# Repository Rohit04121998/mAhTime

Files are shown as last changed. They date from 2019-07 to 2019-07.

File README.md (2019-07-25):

# mAhTime

## Objective 

To calculate the battery life for a device using small batteries and in turn use the data to calculate for any bigger battery.

## Why do we need this?

The capacity of a battery is measured in Ah (ampere-hours, for large batteries) or mAh (milliampere-hours, for small batteries). This is usually mentioned on the battery or in the datasheets provided by the manufacturer. But the capacity changes depending on the age of the battery, operating conditions, slightly different chemical composition, etc. So it affects the final result.

To get the actual capacity (close-enough-value), measuring the same is the method. Different methods are there using which one can measure the capacity, for example, Coulomb counting, Voltage monitoring, etc. (Learn more here or here).

Here we use the second method; monitoring the terminal voltage when a known load (resistive) is connected.

## Method:

The batteries are charged and connected to a custom-designed shield for the ESP8266 microcontroller and a load is selected using a button. The microcontroller logs the terminal voltage read from its pin to the MQTT broker in RPi until the lower cut off voltage for the batteries is reached. The loads are automatically disconnected using logic level p-MOS switches. 

The values read by the microconttrollr is sent to a RPi using a MQTT broker named **mosquitto**. MQTT is a pub-sub based protocol where one device reads and sends the data to a topic and another device subscribes to the same topic to get the data published by the first device. A brief explanation of how values are sent via a broker is explained in the next heading. The recieved data is run through a python script to display the discharge curve and the area under the curve is calculated(area under the V*I v/s t curve is power rating and area under the I v/s t curve is the mAh / Ah of the batteries).

Once again the batteries are charged, but this time, Device Under Test (DUT) is selected instead of a load (using the same microcontroller). The time taken for the DUT to discharge the batteries is found. This can then be used to calculate the life of any battery using ratios ( Eg.: If for X (mAh) it is Y (no. of days) then for Z (mAh)? = YZ/X ).

## MQTT

MQTT is one of the most commonly used protocols in IoT projects. It stands for Message Queuing Telemetry Transport.

  In addition, it is designed as a lightweight messaging protocol that uses publish/subscribe operations to exchange data between clients and the server. Furthermore, its small size, low power usage, minimized data packets and ease of implementation make the protocol ideal of the “machine-to-machine” or “Internet of Things” world.

## WHY MQTT??

MQTT has unique features you can hardly find in other protocols, like:

* It’s a lightweight protocol. So, it’s easy to implement in software and fast in data transmission.
* It’s based on a messaging technique. You know how fast your messenger/WhatsApp message delivery is. MQTT protocol is a similar one.
* Minimized data packets. Hence, low network usage.
* Low power usage. As a result, it saves the connected device’s battery.

## How MQTT works
Like any other internet protocol, MQTT is based on clients and a server. The server is the guy who is responsible for handling the client’s requests of receiving or sending data between each other. MQTT server is called a broker and the clients are simply the connected devices.

#### So:

When a device (a client) wants to send data to the broker, we call this operation a *“Publish”* and the device *"Publisher"*.
When a device (a client) wants to receive data from the broker, we call this operation a *“Subscribe”* and this device as *"Subscriber"*.

  
  
 ## MQTT Components

* *Broker*, which is the server that handles the data transmission between the clients.
* A *Topic*, which is the place a device want to put or retrieve a message to/from.
* The *Message*, which is the data that a device receives “when subscribing” from a topic or send “when publishing” to a topic.
* *Publish*, is the process a device does to send its message to the broker.
* *Subscribe*, where a device does to retrieve a message from the broker.

*By now hopefully you would have an idea how a MQTT network might look or works like.* 

  The common methods used to transfer data are:
  
  * Making use of [test.mosquitto.org](http://test.mosquitto.org/) server as a MQTT broker and sending the data via this server.
  
  * Making use of a common WiFi network to share the data.
  
  * Making one of the ends (i.e either ESP8266 or the RPi) as an *Access Point* and connect the other to it.
  
    The 2nd and the 3rd methods do not use any online brokers. Therefore a broker is to be installed in the RPi. For information on how to install mosquitto broker on your RPi use the link [Getting Started with Mosquitto MQTT Broker on a Raspberry Pi](https://www.youtube.com/watch?v=AsDHEDbyLfg&t=72s).

## Hardware & Firmware:

A microcontroller unit (ESP8266-12E on LOLin board) has an inbuilt ADC (Analog to Digital Converter) with a precision of (1/1024)th of a volt. But the input voltage range is only 0 (0) - 1V (1024). To use this in 0 - 3V range a resistor voltage divider is implemented using precision resistors and an n- MOS switch to enable this voltage divider. The voltage divider is not the one which is present on the LOLin board. Those are not precision resistors, hence the readings may not be accurate. The n-MOS switch is required as the voltage divider acts as another resistive load parallel to the selected load. An OLED display is used to display the selected load, time, etc.

The hardware limits the maximum battery voltage to 3.6V as the battery voltage appears at pin A0 when voltage divider is disabled and the absolute maximum voltage given is 3.6V for ESP8266. The time taken for measurement is determined by the capacity of the battery and the chosen load.

The circuit connections and the designed PCB can be found in the directory PCB_KICAD. The details about the charger and the battery can be found in the 'Charger_hacked' directory. 
Arduino IDE is used to program the microcontroller. The required header files and libraries are in the *upload_voltage* directory.

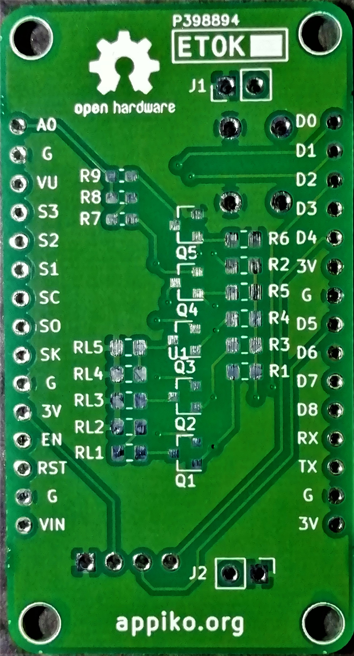
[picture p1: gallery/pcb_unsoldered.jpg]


### <p align="center">Fig 1. Unsoldered PCB</p>

PCB Front             |  PCB Back              
:-------------------------:|:-------------------------:
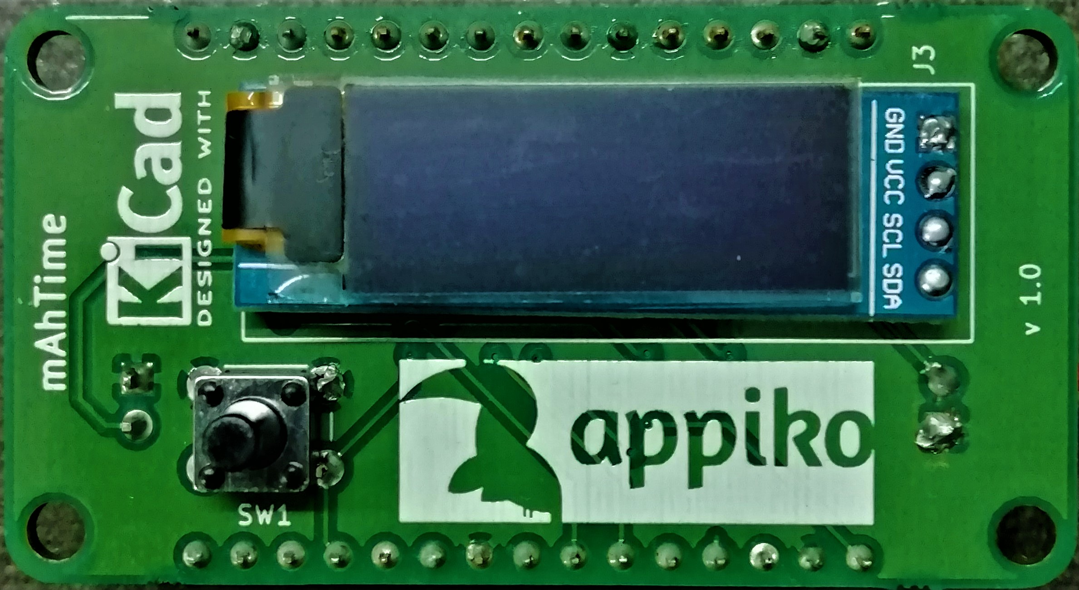
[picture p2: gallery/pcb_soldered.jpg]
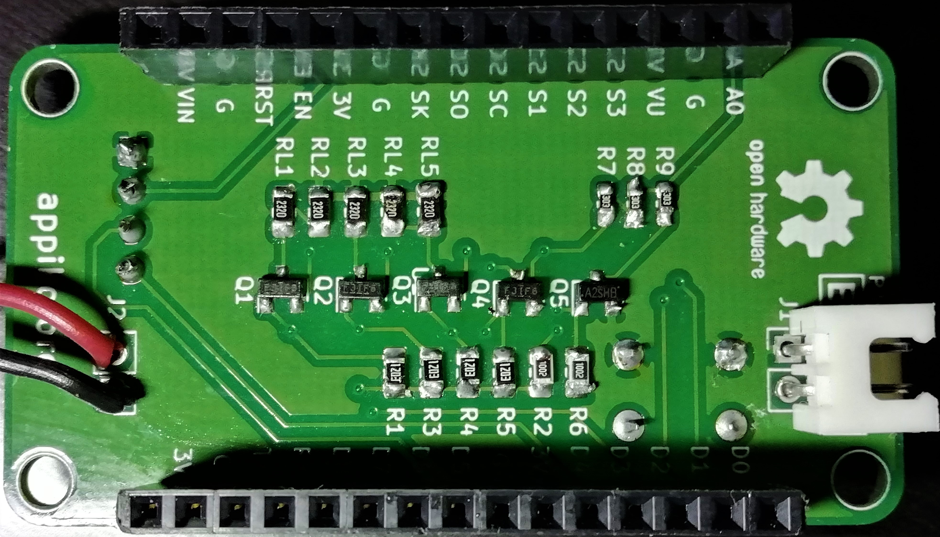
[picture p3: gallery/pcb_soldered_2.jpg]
 |   

### <p align="center">Fig 2. Soldered PCB</p>

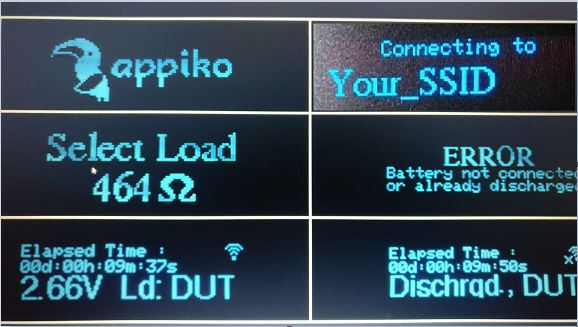
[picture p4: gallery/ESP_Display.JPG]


### <p align="center">Fig 3. Display</p>

## Code:

* In the *upload_voltage.ino* file, **Vbat** variable is used to store the voltage value. The queue is sized to hold a maximum of 1000 values. Here, the value is stored and sent every 4 seconds.

* To get the date and time info from the ESP8266, *NTTP Client* has been used . The *getFormattedDate()* function gives the date and time format as 2018-05-28T10:00:13Z. So modifications were done and the final output was  2018-05-28_10:00:13. This was further modified in the *plot.py* by replacing ':' with 'H', 'M' and 'S'. This was then appended to the *.csv* file having the load value as its initial name.

* The code is made such that a short press of the button is conssidered as next option and a long press is considered as select. The long press for one of the load values sets the value of variable *seleted* to a umber between 1 and 8. The load is selected according to the value of variable *selected* in the function *LoadVal*. The function *attachLoad* attaches the load and changes the state of the mosfets accordingly. The discharging of the battery starts as soon as the load is attached.

* Before any value is sent through MQTT, the variable *filename* which contains the device ID, load, date and time with the .csv extension is published to inform the subscriber that a new discharge cycle has started and to create a new CSV file by the name of the variable sent. Only after the filename are the voltage values to be sent.

* Once all the values are sent over through MQTT, a "Fully Discharged" message is sent stating that te experiment's finished.

* The code for MQTT subscribe is a simple code which tells the interpreter what to do when the connection with the MQTT broker is established and when a message is recieved. The funtion on_connect will be executed as soon as connection is established. The on_message funtion is executed as soon as a message is received. The messaged is checked for a **.csv** extension and a new CSV file is created if the result of this comparision is positive.

* This message with a .csv extension contains the ID of the device which published the message,the load selected, date and time of the moment a load is selected. The name of the new CSV file created contains only load,date and time(format containing 'H' 'M' and 'S' specified in one of the above points. Here data and time are included to differentiate between experiments conducted on the same day.

* The voltage values received are added to this file along with the time elapsed. At the end of the experiment "FUlly Discharged" message is recieved once and is added to the file informing the plotter that the experiment is finished and the mAh value can be calculated.

* In the script Plot_value.py **FuncAnimate** function is used to create an interactive mode i.e to plot a real time graph. The mAh value of the battery is shown only when the message "Fully Discharged" intercepts by the interpreter.

## Result:

  The result of the experments need not be the same everytime. The mAh value might change if the battery is not fully charged before the start of the experiment. The time taken for the discharge and the numbeer of voltage values recorded varies if a different load value is used or if the initial voltage of the battery is different.

The device was tested for 3 different loads and the graph plotted were as follows:

**Load**             |  093 Ohms             |  161 Ohms(Not fully charged)                                   
:-------------------------:|:-------------------------:|:-------------------------:
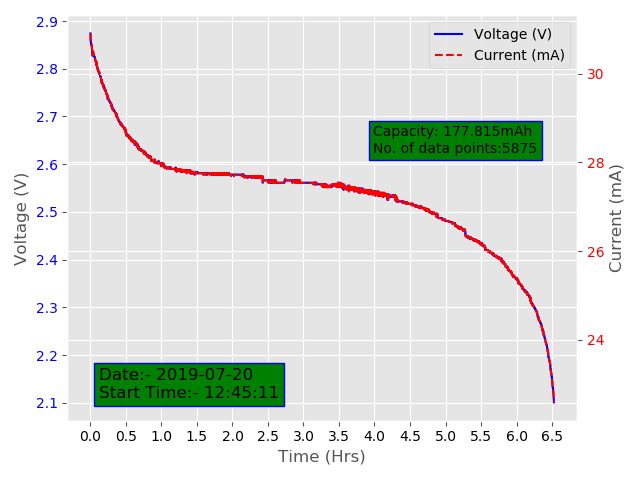
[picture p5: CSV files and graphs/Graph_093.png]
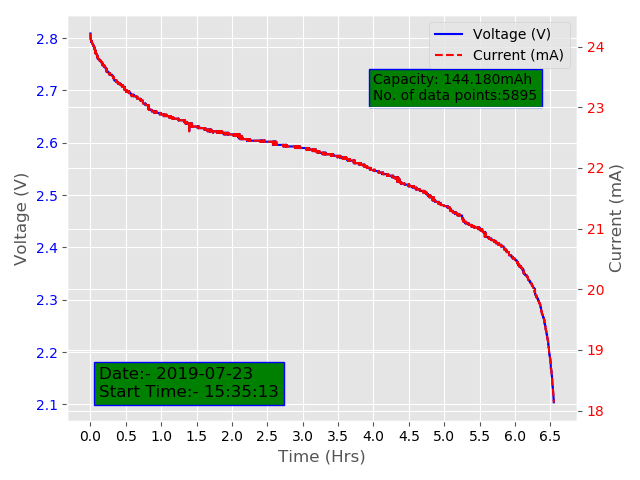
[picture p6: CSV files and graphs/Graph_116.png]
**Graph**|  | 

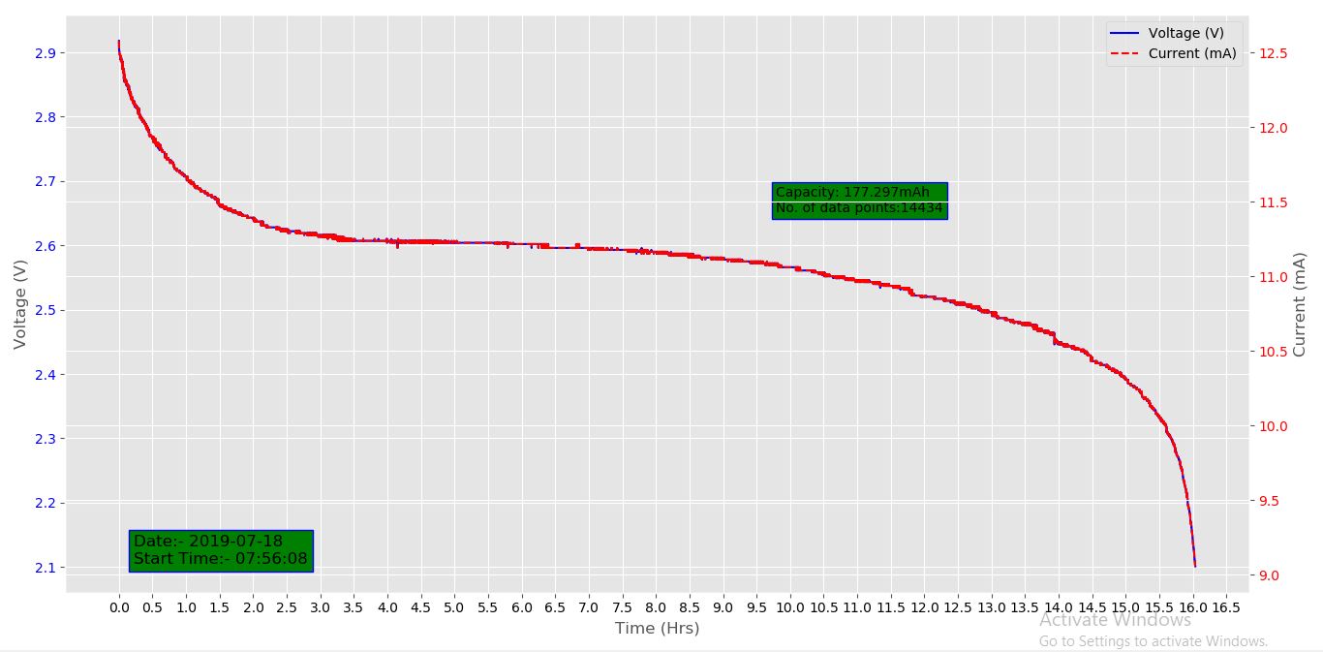
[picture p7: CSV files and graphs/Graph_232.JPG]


### <p align="center">232 Ohms</p>

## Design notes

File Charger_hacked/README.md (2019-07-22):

## Which battery and charger?

*Tuscan Gold* (model: TG-003) NiCd, NiMH battery charger to charge the *GP Battery* (17AAAH, 1.2V, C = 170mAh, NiMH,*1/3rd AAA*).

1/3rd AAA battery

## Why the charger needs modifications?

Rated current capacity of the charger for the AAA size batteries (2S) is 100mA which is NOT the recommended amount of current for the 
mentioned tiny batteries. For the NiMH battery it is recommemnded to charge at 0.1C or below (usually 0.05C) but very low current through 
the batteries will result in a long charge duration.  Another problem with these tiny batteries is that they can not be installed in the given 
slot as that is for full sized AAA batteries.

## What are the modifications?

1. The over current problem was solved by adding a 147ohm resistor is series with the charger terminals and achieved a current flow of around 
12mA (~0.07C). Thses batteries (NiMH/NiCd) don't have floating terminal potential like Li-Ion batteries. So the change in voltage due to the 
added resistor across the terminals doesn't matter actually.
2. A pair of Molex connector was added to the charger with the wires connecting the terminals (One connector for 2S configuration. Resistor and
connections are invisible).

Hacked charger

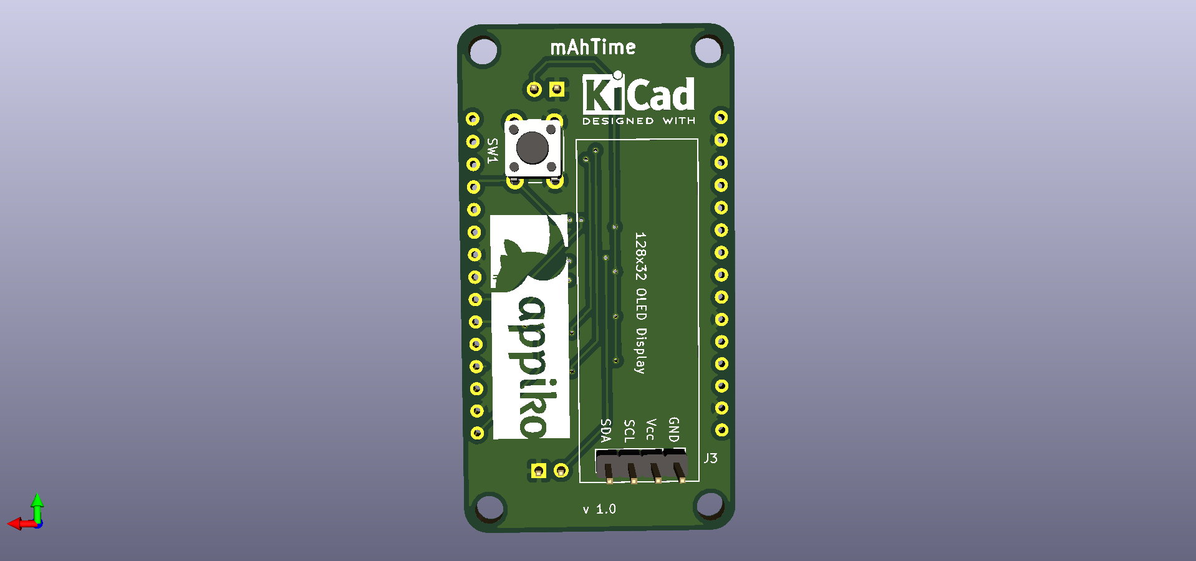
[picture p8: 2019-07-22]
PCB_KiCAD/images/pcb_3D_view_back.png

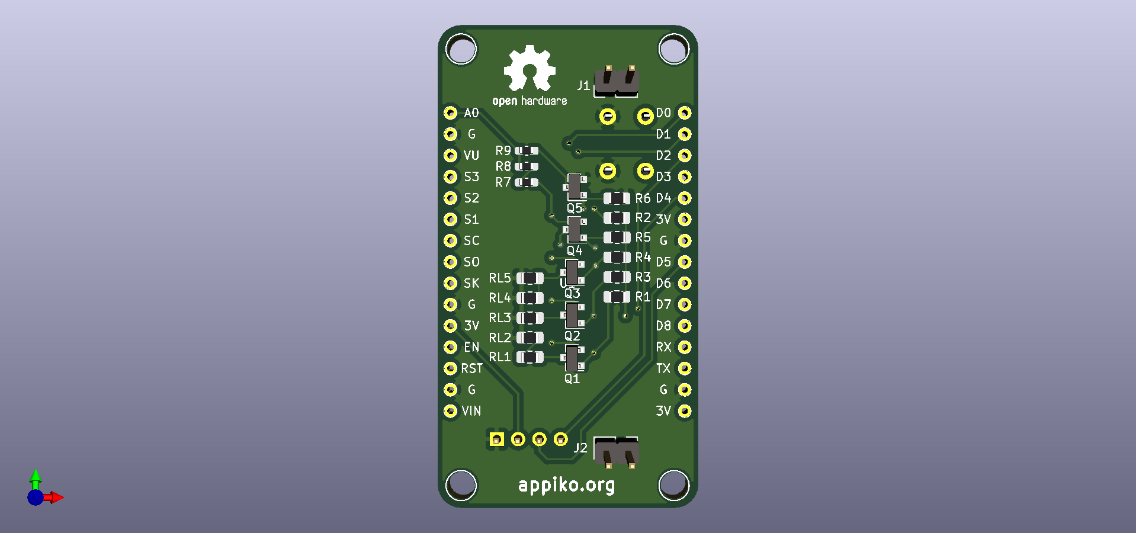
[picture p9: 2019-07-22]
PCB_KiCAD/images/pcb_3D_view.png

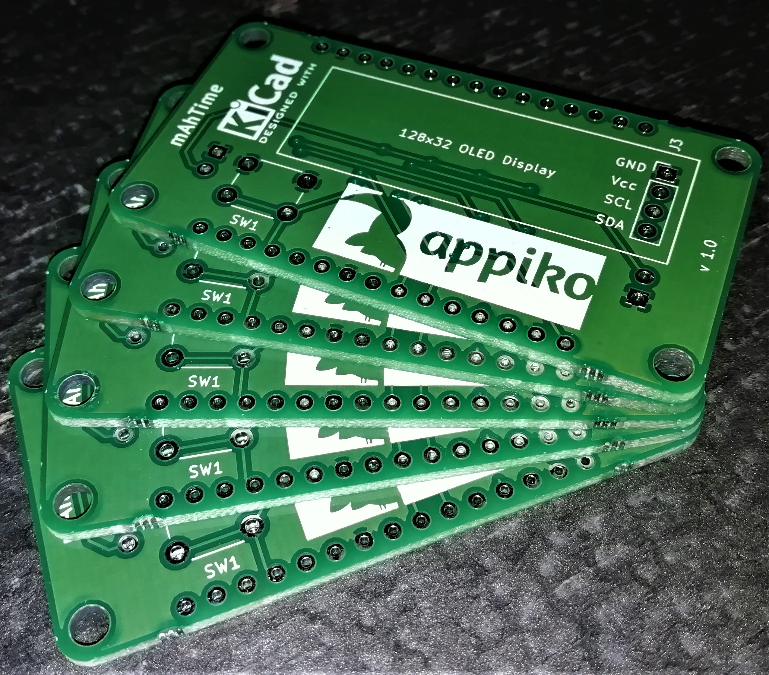
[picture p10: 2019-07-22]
gallery/pcb_stacked.jpg

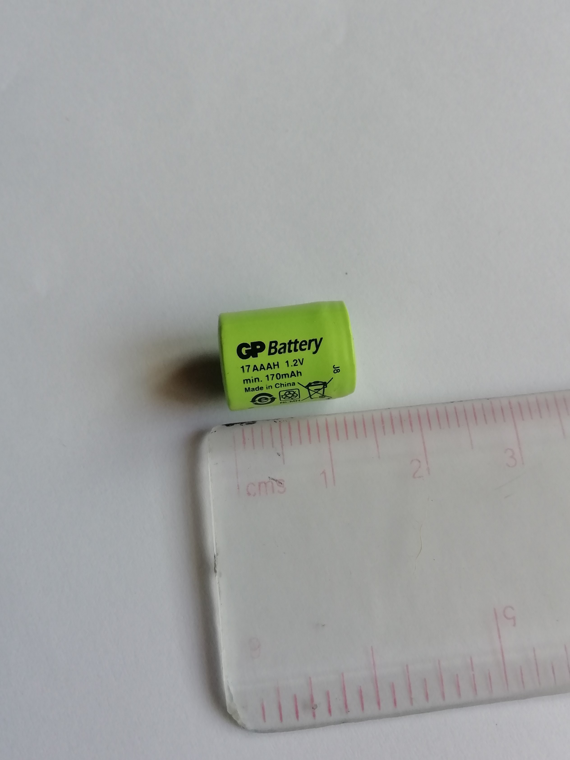
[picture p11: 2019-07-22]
Charger_hacked/battery_GP.jpg

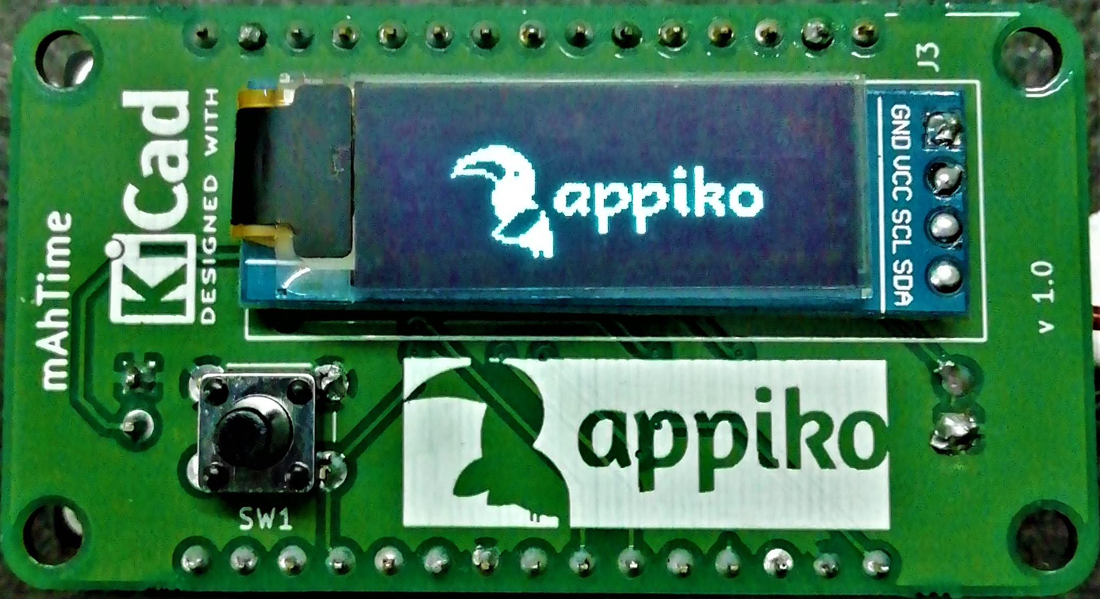
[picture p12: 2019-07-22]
gallery/pcb_powered.jpg

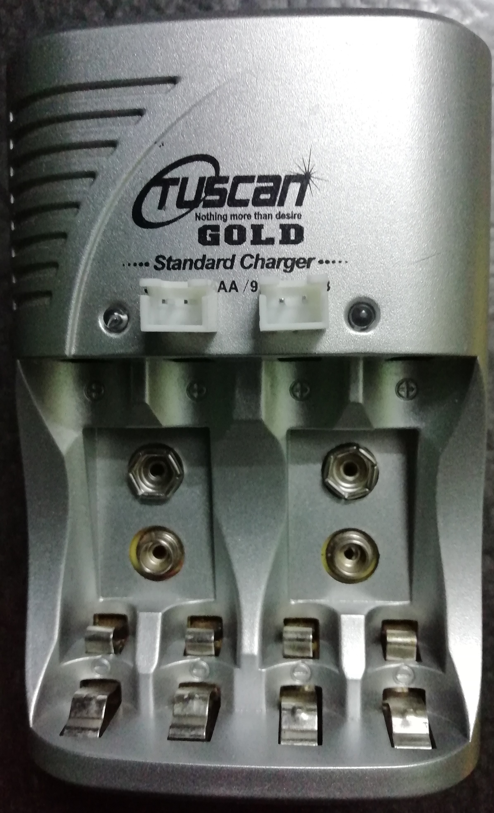
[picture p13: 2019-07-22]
Charger_hacked/charger_tuscan.jpg

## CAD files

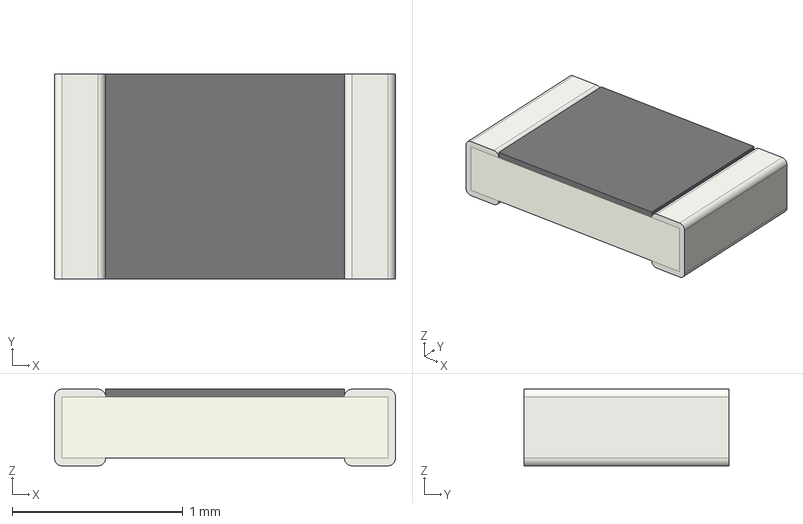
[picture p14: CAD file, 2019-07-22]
PCB_KiCAD/3D_models/R_0805_2012Metric.step
2.00 x 1.20 x 0.45 mm

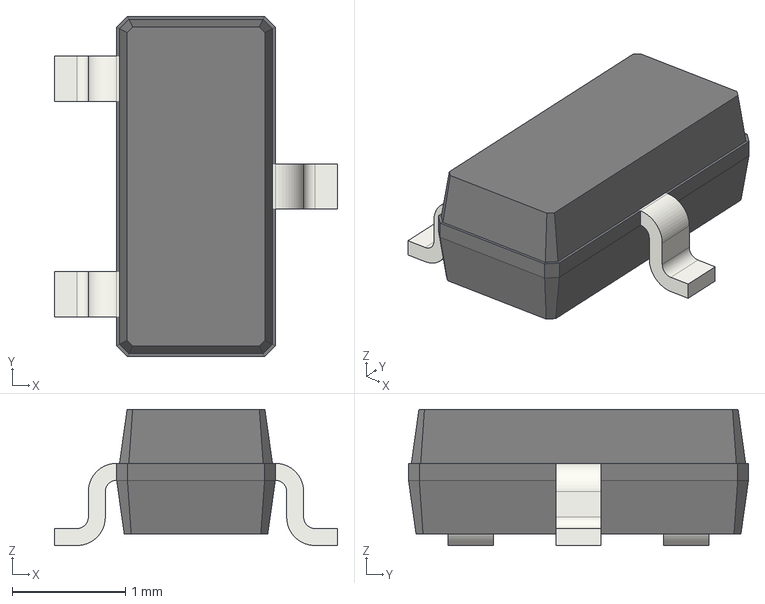
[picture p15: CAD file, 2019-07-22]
PCB_KiCAD/3D_models/SOT-23.step
2.50 x 3.00 x 1.20 mm

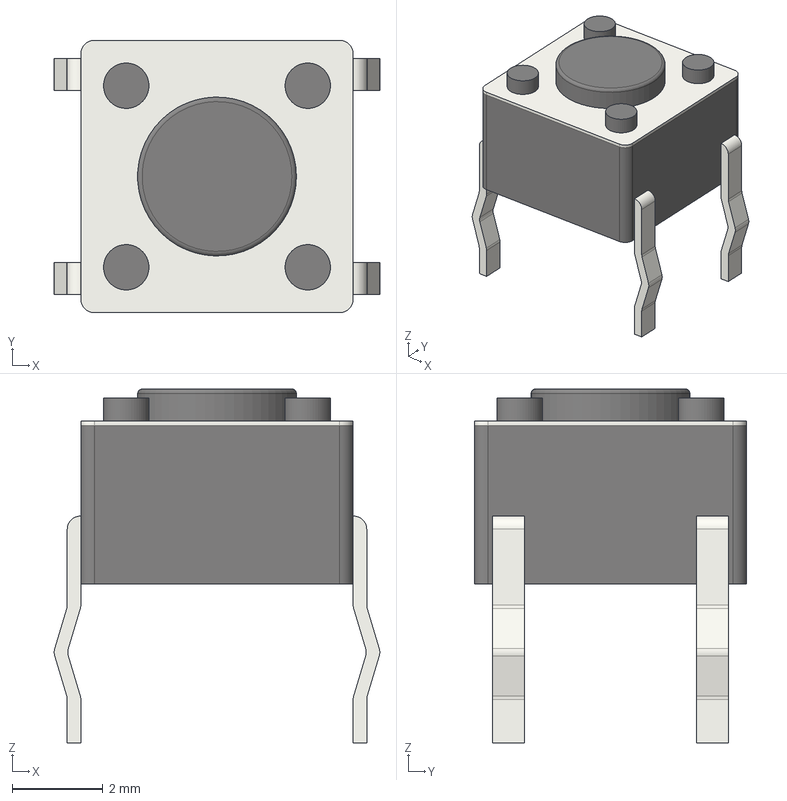
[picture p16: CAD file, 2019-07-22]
PCB_KiCAD/3D_models/SW_PUSH_6mm.step
7.17 x 6.00 x 7.80 mm

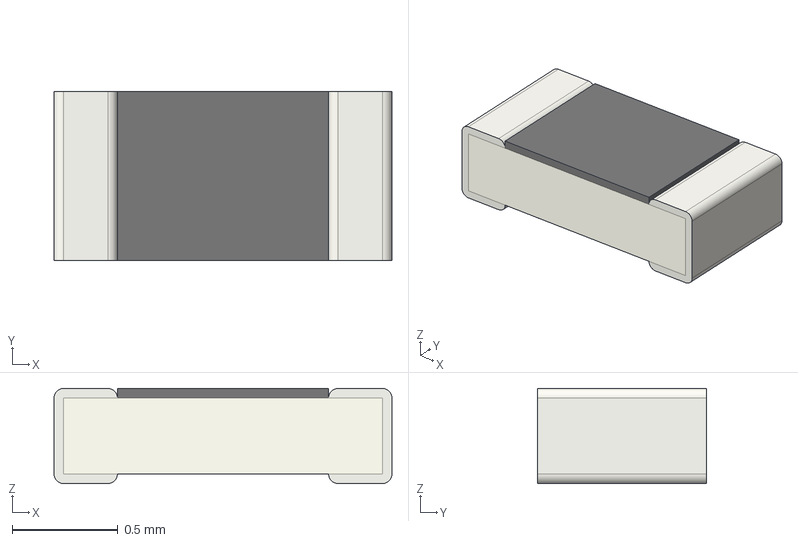
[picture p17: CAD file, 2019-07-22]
PCB_KiCAD/3D_models/R_0603_1608Metric.step
1.60 x 0.8 x 0.45 mm

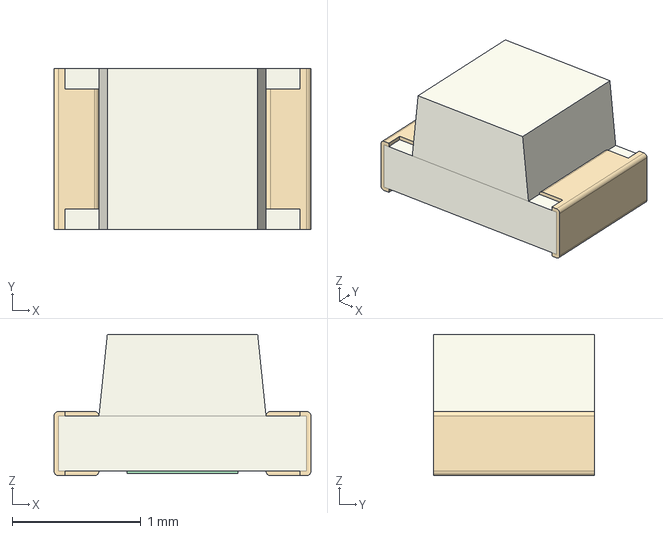
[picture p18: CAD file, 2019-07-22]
PCB_KiCAD/3D_models/LED_0805_2012Metric.step
2.00 x 1.25 x 1.10 mm

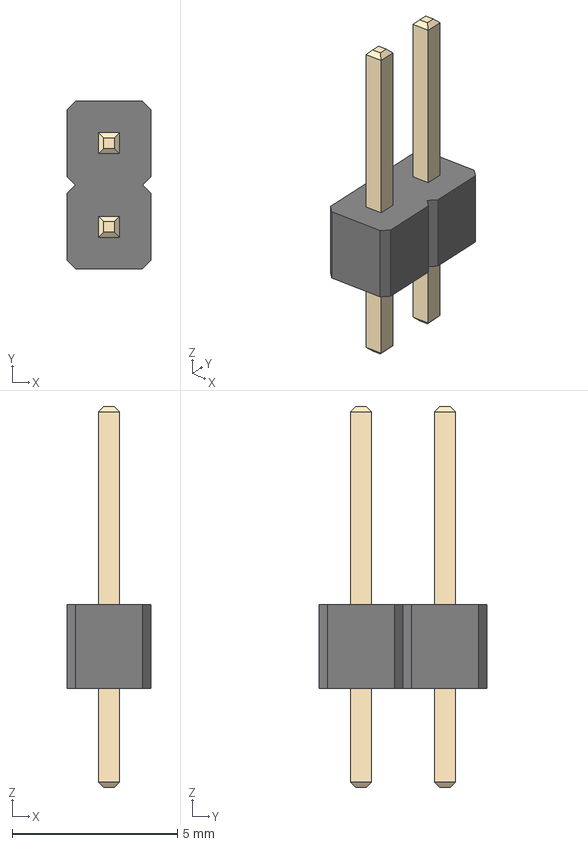
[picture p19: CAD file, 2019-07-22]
PCB_KiCAD/3D_models/PinHeader_1x02_P2.54mm_Vertical.step
2.54 x 5.08 x 11.5 mm

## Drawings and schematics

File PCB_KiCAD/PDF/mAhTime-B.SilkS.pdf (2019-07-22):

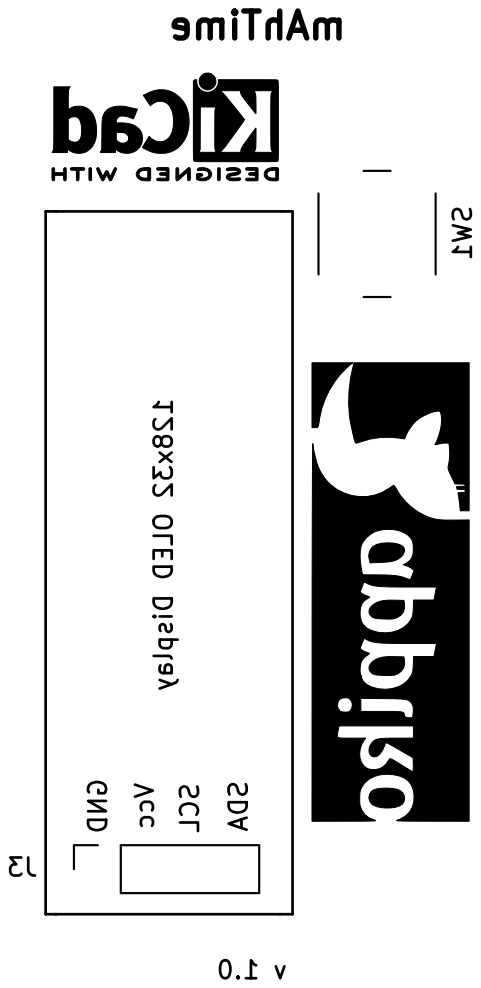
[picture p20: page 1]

J3 128x32 OLED Display GND Vcc SCL SDA SW1

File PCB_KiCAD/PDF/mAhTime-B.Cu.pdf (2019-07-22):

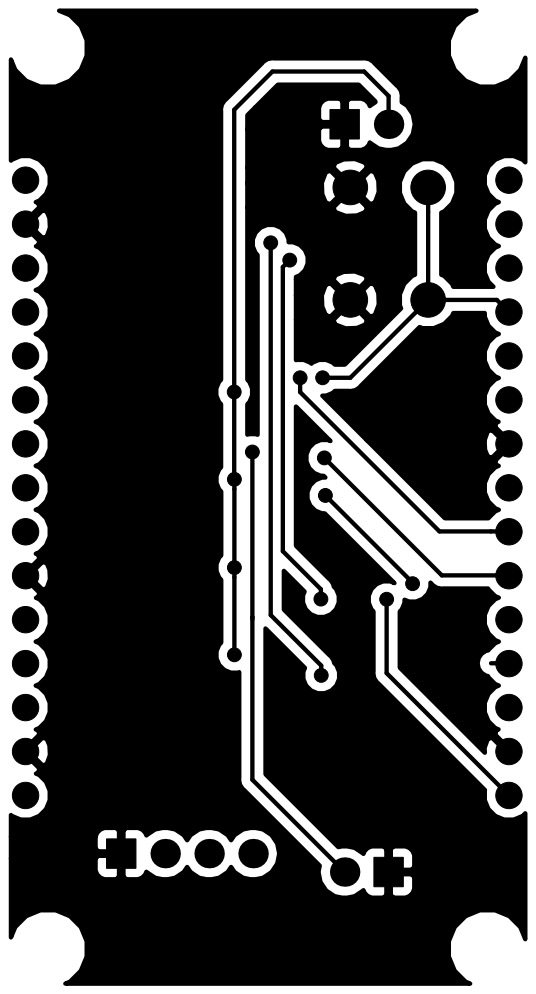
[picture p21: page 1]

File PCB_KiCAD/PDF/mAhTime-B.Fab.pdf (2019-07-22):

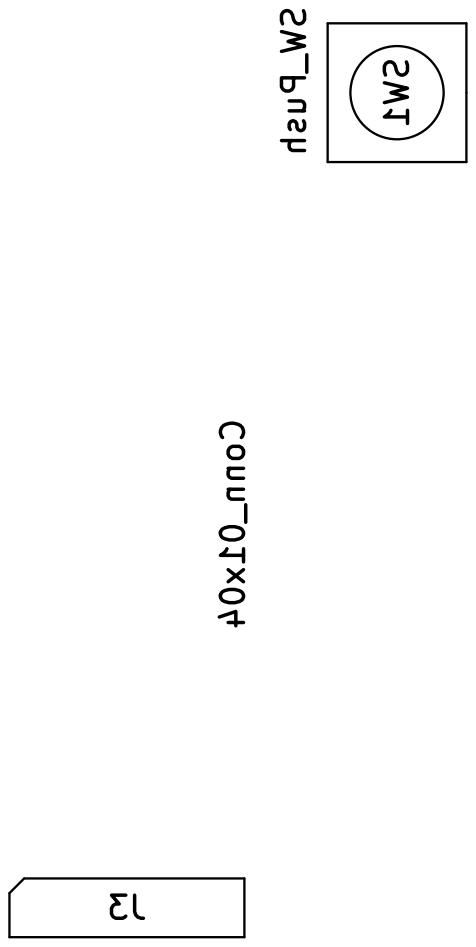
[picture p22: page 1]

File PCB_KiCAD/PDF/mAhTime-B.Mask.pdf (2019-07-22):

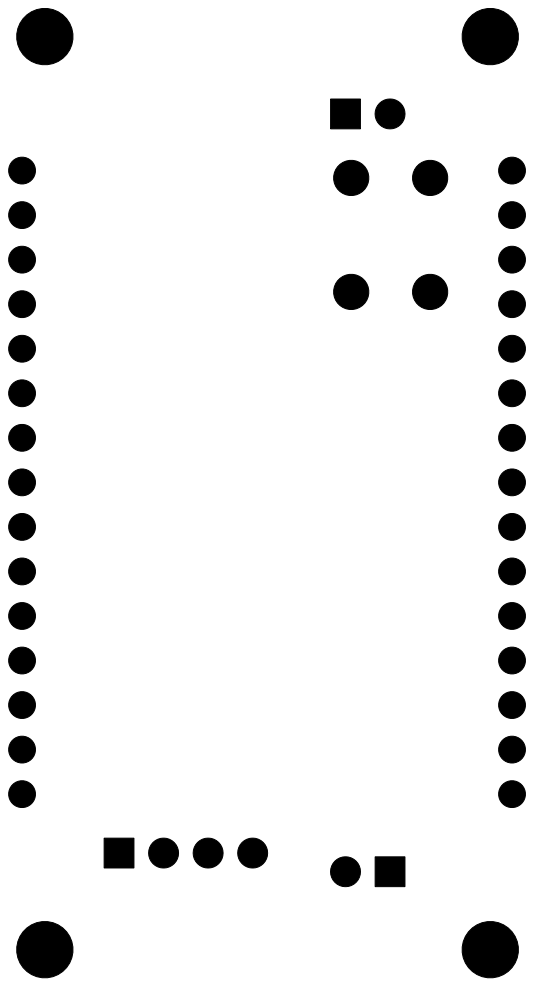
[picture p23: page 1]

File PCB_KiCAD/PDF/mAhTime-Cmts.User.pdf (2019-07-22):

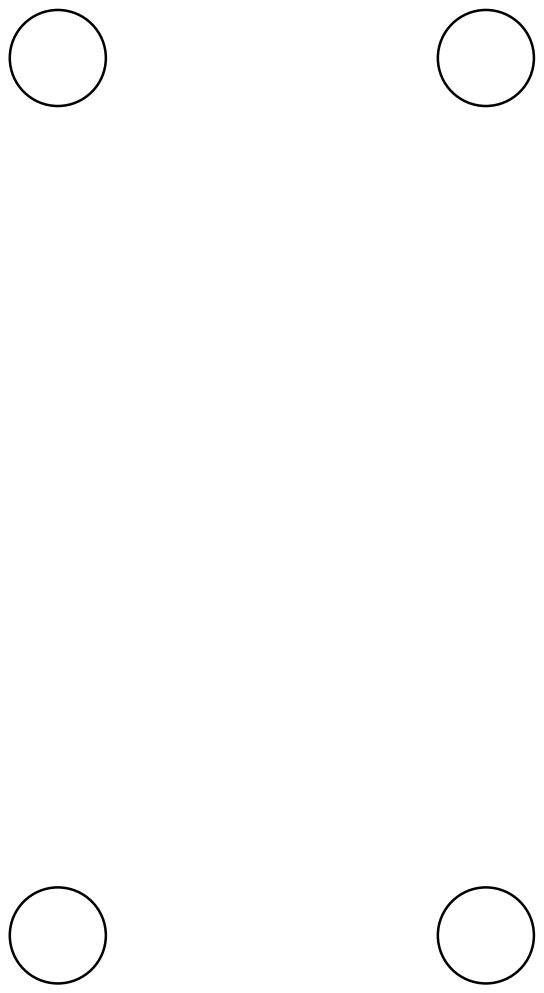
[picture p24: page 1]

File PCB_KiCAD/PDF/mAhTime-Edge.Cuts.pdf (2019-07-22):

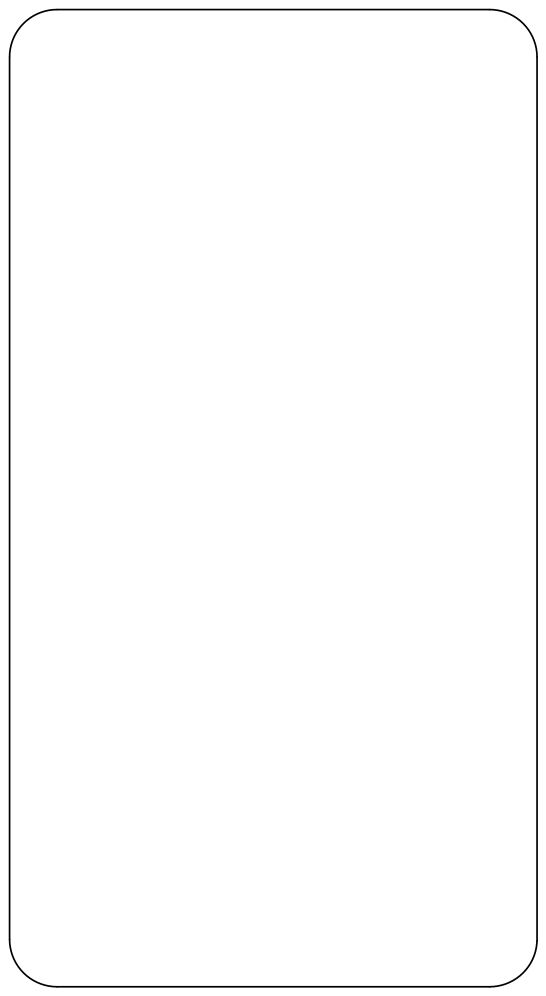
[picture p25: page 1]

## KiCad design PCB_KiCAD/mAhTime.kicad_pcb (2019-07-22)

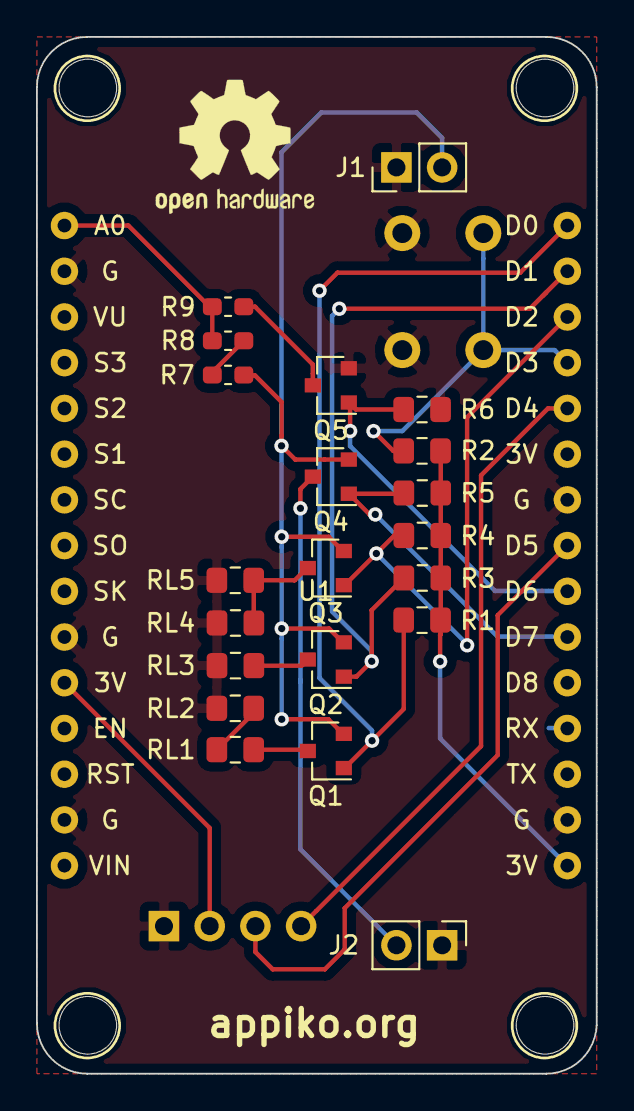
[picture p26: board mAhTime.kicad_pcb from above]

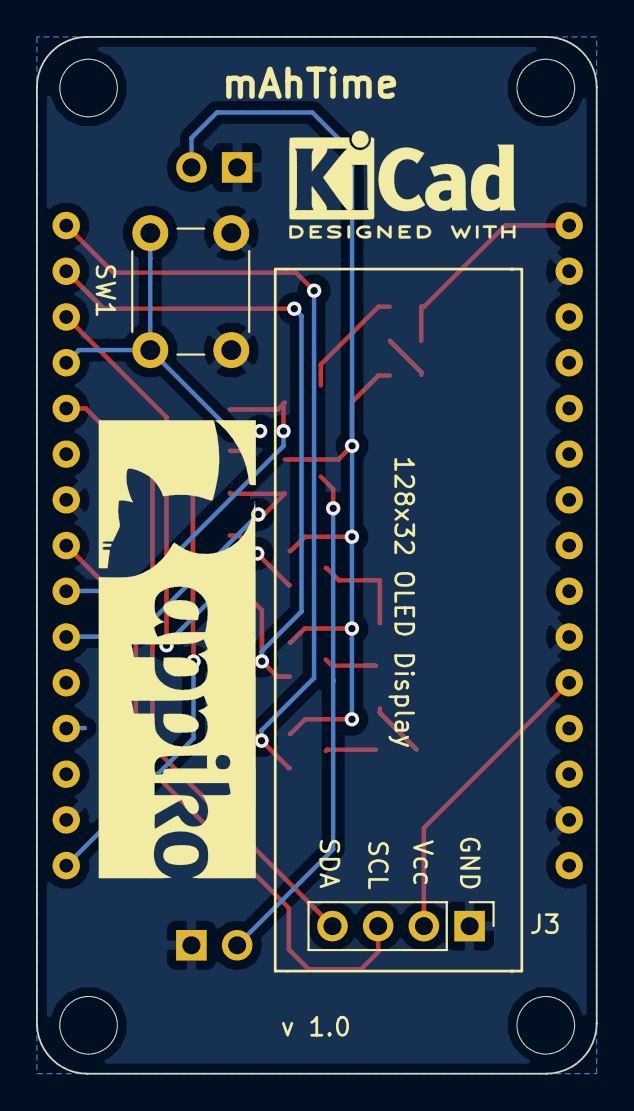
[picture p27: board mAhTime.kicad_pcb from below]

Board: 2 copper layers, 31.1 x 57.6 mm, 28 parts (2 on the bottom side), 19 nets.

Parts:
H1, H2, H3, H4: MountingHole; MountingHole_3.2mm_M3_ISO7380
J1: BATTERY; PinHeader_1x02_P2.54mm_Vertical
J2: DUT; PinHeader_1x02_P2.54mm_Vertical
J3: Conn_01x04; 128x32_OLED_Display
Q1, Q2, Q3, Q4: IRLML6401TRPBF; SOT-23
Q5: SI2302; SOT-23
R1, R3, R4, R5: 100k; R_0805_2012Metric_Pad1.15x1.40mm_HandSolder
R2: 1k; R_0805_2012Metric_Pad1.15x1.40mm_HandSolder
R6: 10k; R_0805_2012Metric_Pad1.15x1.40mm_HandSolder
R7, R8, R9: 30k; R_0603_1608Metric_Pad1.05x0.95mm_HandSolder
RL1, RL2, RL3, RL4, RL5: 232; R_0805_2012Metric_Pad1.15x1.40mm_HandSolder
SW1: SW_Push; SW_PUSH_6mm
U1: NodeMCU1.0(ESP-12E); NodeMCU-LoLinV3_without_border

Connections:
/Ctrl1: Q1.1, R1.2, U1.30
/Ctrl2: Q2.1, R3.2, U1.29
/Ctrl3: Q3.1, R4.2, U1.28
/Ctrl4: Q4.1, R5.2, U1.21
/En_VD: Q5.1, R6.2, U1.22
/SCL: J3.3, U1.23
/SDA: J3.4, U1.26
/SW: R2.2, SW1.1, U1.27
/Vbat: J1.2, Q1.2, Q2.2, Q3.2, Q4.2, R7.1
/Vcc: J3.2, R1.1, R2.1, R3.1, R4.1, R5.1, U1.11, U1.16, U1.25
/Vin: R8.2, R9.1, U1.1
/dut: J2.2, Q4.3
GND: J1.1, J2.1, J3.1, Q5.2, R6.1, RL2.2, RL3.2, RL4.2, RL5.2, SW1.2, U1.2, U1.10, U1.14, U1.17, U1.24
unnamed: Q1.3, RL1.1
unnamed: Q2.3, RL3.1
unnamed: Q3.3, RL4.1, RL5.1
unnamed: Q5.3, R9.2
unnamed: R7.2, R8.1
unnamed: RL1.2, RL2.1

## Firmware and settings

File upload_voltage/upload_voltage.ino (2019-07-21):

/********************************************************************************
BSD 3-Clause License

Copyright (c) 2019, Sudheendra Hegde
All rights reserved.

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
1. Redistributions of source code must retain the above copyright notice, this
   list of conditions and the following disclaimer.

2. Redistributions in binary form must reproduce the above copyright notice,
   this list of conditions and the following disclaimer in the documentation
   and/or other materials provided with the distribution.

3. Neither the name of the copyright holder nor the names of its
   contributors may be used to endorse or promote products derived from
   this software without specific prior written permission.

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
*****************************************************************************************/
#include "DateTime.h"
#include "config.h"
#include "DischargeBattery.h"

char V_val[10];
char file[50];
float Vbat = 0, saved = 0;
float last = -1;
int stat = 0;
void setup() {
  //set pinMode
  pinMode(LOAD1,OUTPUT);  //load resistance of 464ohm
  pinMode(LOAD2,OUTPUT);  //load resistance of 232ohm
  pinMode(LOAD3,OUTPUT);  //load resistance of 116ohm
  pinMode(DUT,OUTPUT);       //load is the Device Under Test (DUT)
  pinMode(SW,INPUT_PULLUP);         //push button (active high input)
  pinMode(EN_VOLTAGE_DIVIDER,OUTPUT);  //pin connected to gate of the mosfet which enables the voltage divider
  pinMode(Vin,INPUT);
  
  turnOffAllLoad();   //make sure all loads are off initially
  Wire.begin(SDA_PIN,SCL_PIN);
  display.begin(SSD1306_SWITCHCAPVCC, 0x3C);            // SSD1306_SWITCHCAPVCC = generate display voltage from 3.3V internally
  if(!display.begin(SSD1306_SWITCHCAPVCC, 0x3C)) {      // Address 0x3C for 128x32
    for(;;);                                            // SSD1306 allocation failed, Don't proceed, loop forever
  }
  display.clearDisplay();                       //clear the display buffer
  display.setRotation(2);                       //rotate 180 degerees
  display.drawBitmap(                           //draw bitmap image
    (display.width()  - logo_width ) / 2,       //align it at the center
    (display.height() - logo_height) / 2,
    logo, logo_width, logo_height, 1);
  display.display();                            //actually display the logo
  delay(2000);
  display.clearDisplay();        //clear the display buffer
  display.setTextSize(1);
  display.setTextColor(WHITE);
  display.setCursor(3,0);
  display.println("    Connecting to   ");
  display.setFont(&FreeSerif9pt7b);
  display.setCursor(0,24);
  display.println(ssid);
  display.display(); // actually display all of the above
  
   // Connect to the WiFi
  WiFi.begin(ssid, wifi_password);
  
  // wait for a connection
  while(WiFi.status() != WL_CONNECTED) {
    delay(500);
  }
  display.clearDisplay();
  display.setCursor(25,18);
  display.println("Connected");
  if (client.connect(clientID, mqtt_username, mqtt_password)) {
    display.println("Connected to MQTT Broker!");
  }
  else {
    display.println("Connection to MQTT Broker failed...");
  }
  
  display.display();
  delay(1000);
  queueInit();     //initialize queue
  checkBattery();   //verify whther connected battery has voltage > VLowerCutOff
  loadSelect();           //let the user select load / DUT
  display.setFont(&FreeSans9pt7b);  //change font to Sans
  StartTime = millis();     //save the starting time
}

void loop() {
  client.loop();
  _time = millis();
  
  if( !ONCE_DISCHARGED )  
    Vbat = readVoltage();
  if( !(Vbat < VLowerCutOff) )
    enqueue(Vbat);    //enqueue the values
  
  if(Vbat < VLowerCutOff)  {   //if the battery Vbat falls below the lower cut off
      ONCE_DISCHARGED = 1;         //clear the ONCE_DISCHARGED so that it does not oscillate when terminal Vbat rises slightly.
      turnOffAllLoad();    //turn OFF ALL loads when batteries got fully discharged.
      EndTime = millis();  //store end time
      DISP_ON = 1; //display that the batteries got discharged
      displayedAt = millis ();  //this is required when display is turned on using DISP_ON
      while(1){
        if (rear != front)    //queue is not empty
          if((!(WiFi.status() < WL_CONNECTED)) && client.connect(clientID, mqtt_username, mqtt_password)) {
            filename.toCharArray(file,50);
            if(stat == 1){
            saved = dequeue();            //read value from the queue 
            dtostrf(saved,4,3,V_val);     //convert float to char array
            client.publish(mqtt_topic, V_val);    //publish value to the MQTT broker
              }
          else if(client.publish(mqtt_topic,file) && stat == 0){  // The values read can be sent only after sending  filename
            stat = 1;
            }
          }
         if(rear == front && discharged == 0){  // This message is sent only after queue is empty and only once per discharge
          if(client.publish(mqtt_topic,"Fully Discharged"))
          discharged == 1;
          }

        checkForUpdate();
        yield();  
     }
  }
  
  while( (millis() - _time) < 4000){    //wait for 4 seconds
      checkForUpdate();
      if (rear != front)    //queue is not empty
        if((!(WiFi.status() < WL_CONNECTED)) && client.connect(clientID, mqtt_username, mqtt_password)) {
           filename.toCharArray(file,50);
           if(stat == 1){
            saved = dequeue();            //read value from the queue 
            dtostrf(saved,4,3,V_val);     //convert float to char array
            client.publish(mqtt_topic, V_val);    //publish value to the MQTT broker
            }
          else if(client.publish(mqtt_topic,file) && stat == 0){
            stat = 1;
            }
          }

  
      yield();
  }
}

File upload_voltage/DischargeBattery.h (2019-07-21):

#include <SPI.h>
#include <Wire.h>
#include <ESP8266WiFi.h>
#include <Adafruit_GFX.h>
#include <Adafruit_SSD1306.h>
#include "displaySymbols.h"
#include <Fonts/FreeSerif9pt7b.h>
#include <Fonts/FreeSans9pt7b.h>

static const char PROGMEM id[] = "DeviceID";  // This stores as Flash
#define BUFF_SIZE 1000   //max size of the buffer
#define LOAD1 16        //load resistance of 564ohm
#define LOAD2 5        //load resistance of 232ohm
#define LOAD3 4       //load resistance of 116ohm
#define DUT   13       //load is the Device Under Test (DUT)
#define SW   0           //define the pin connected to the push button
#define SCL_PIN  14      //define pins for I2C communication
#define SDA_PIN  2
#define EN_VOLTAGE_DIVIDER 12 //the gate of a mosfet which enables the voltage divider for analog input.
#define Vin A0            //input: battery voltage 
#define SCREEN_WIDTH 128 // OLED display width, in pixels 
#define SCREEN_HEIGHT 32 // OLED display height, in pixels
const char LOADSTR1[]="464"; //define string containing load values
const char LOADSTR2[]="232";
const char LOADSTR3[]="155";
const char LOADSTR4[]="116";
const char LOADSTR5[]="093";
const char LOADSTR6[]="077";
const char LOADSTR7[]="066";
const char LOADSTR8[]="DUT";
String filename = "";
int discharged = 0; // Flag to check discharge condition
const float VLowerCutOff = 2.100000;  //define the lower cut off voltage or the end of discharge voltage for the battery
const int Vin_max = 3;           //maximum voltage that can be given as analog input
const int Vin_min = 0;           //minimum voltage that can be given as analog input
int selected = 0;                //to store the previously selected load
int front;                       //front index of queue (next empty location)
int rear;                        //rear index of queue  (first filled location)
int typeOfPress = 0;              //store whether long press or short press
float Queue[BUFF_SIZE];           //buffer stucture for storing the values if connection is lost
unsigned long int _time, CurTime, StartTime, EndTime = 0, displayedAt = 0;
unsigned short int days = 0, hours = 0, minutes = 0, seconds = 0;  //variables to store elapsed time
boolean DISP_ON = 1;    //flag to store whether to keep display on or off (cleared)
boolean ONCE_DISCHARGED = 0;   //flag to save once the batteries get discharged
boolean DISP_CLEAR_REQUIRED = 0;

Adafruit_SSD1306 display(SCREEN_WIDTH, SCREEN_HEIGHT, &Wire);    //define display object

void queueInit() {     //initialize pointers (queue is empty)
  front = 0;
  rear = 0;
  for (int i; i < BUFF_SIZE; i++)
    Queue[i] = 0;
}

void enqueue(float V) {   //write a value to the buffer
  if( front == (BUFF_SIZE - 1) )    //if queue is full
    front = 0;                      //store again in first position (circular behavior)
  Queue[front] = V;                  
  front++;                          //increment to point to next empty location
}

float dequeue() {     //read value from the buffer
  float val;
    val = Queue[rear];
    rear++;         //increment rear to point to next filled location
    if ( rear == BUFF_SIZE )
      rear = 0;   //if overflows set it back to 0 (circular behavior)
  return val;
}

void turnOffAllLoad() {     //turns off all the loads
  digitalWrite(LOAD1,HIGH);
  digitalWrite(LOAD2,HIGH);
  digitalWrite(LOAD3,HIGH);
  digitalWrite(DUT,HIGH);
}

float readVoltage() {  //reads voltage at Vin by enabling the voltage divider
  int v;
  digitalWrite(EN_VOLTAGE_DIVIDER, HIGH);
  v=analogRead(Vin);
  digitalWrite(EN_VOLTAGE_DIVIDER, LOW);
  return ((float(Vin_max - Vin_min)*v)/1024);
}

void checkBattery() {
  float checkVoltage;
  checkVoltage = readVoltage();
  if (checkVoltage < VLowerCutOff) {   //if the read voltage is less than lower cut off display error message
    display.clearDisplay();
    display.setFont(&FreeSerif9pt7b);
    display.setCursor(35,12);
    display.print("ERROR");
    display.setFont();
    display.setCursor(0,14);
    display.print("Battery not connected\nor already discharged");
    display.display();
    while (checkVoltage < VLowerCutOff) {
      checkVoltage = readVoltage();
      delay(500);
    }
  }
  return;
}

int buttonPressed() {     //function to detect if the button is pressed / not pressed / long pressed 
  long int EndTime0, StartTime0;
  StartTime0 = millis();
  if(!digitalRead(SW)) {       //if button is pressed it gives 'LOW' on the pin
    delay(10);                //debounce
    if(!digitalRead(SW)) {     //verify again
        while(!digitalRead(SW)) {    //keep looping until the button is released
          delay(0);                //avoid rebooting of the MCU
        }
        EndTime0 = millis();
        if((EndTime0 - StartTime0) >= 1950 )
          return 2;         //2 means long press (about 2 sec.)
        else
          return 1;         //1 means short press
    }
    else return 0;          //0 means button is not pressed
  }
  else return 0;            //0 means button is not pressed
}
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

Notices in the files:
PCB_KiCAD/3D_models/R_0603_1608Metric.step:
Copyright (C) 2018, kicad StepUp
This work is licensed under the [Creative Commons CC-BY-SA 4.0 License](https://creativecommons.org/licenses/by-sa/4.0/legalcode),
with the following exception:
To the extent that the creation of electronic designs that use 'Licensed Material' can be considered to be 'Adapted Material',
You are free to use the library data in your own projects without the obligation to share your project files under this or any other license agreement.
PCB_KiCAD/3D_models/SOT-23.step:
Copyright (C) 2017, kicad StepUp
